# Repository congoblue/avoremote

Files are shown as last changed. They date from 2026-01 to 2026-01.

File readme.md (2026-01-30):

For Arduino Nano R4

Emulates mouse to click on a specific absolute screen location when physical button pressed.

Requires library https://github.com/jonathanedgecombe/absmouse

To program button positions, hold down REC button for 10 seconds. Mouse will move to top left of screen
and start to jiggle. Use sliders as X/Y to position the mouse pointer where required for each button then 
press the physical hardware button to record the position.

Move to REC button screen location and hold down REC button again for 10 seconds to exit program mode.

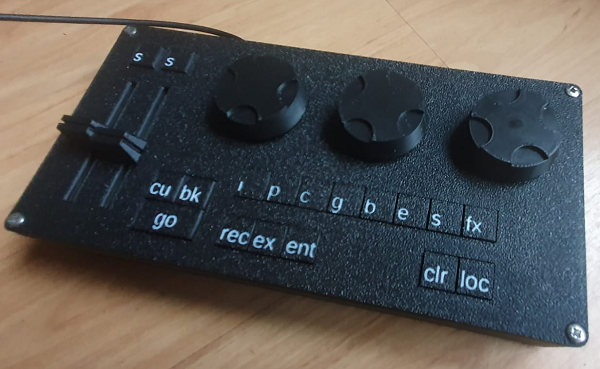
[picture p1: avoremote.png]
prototype


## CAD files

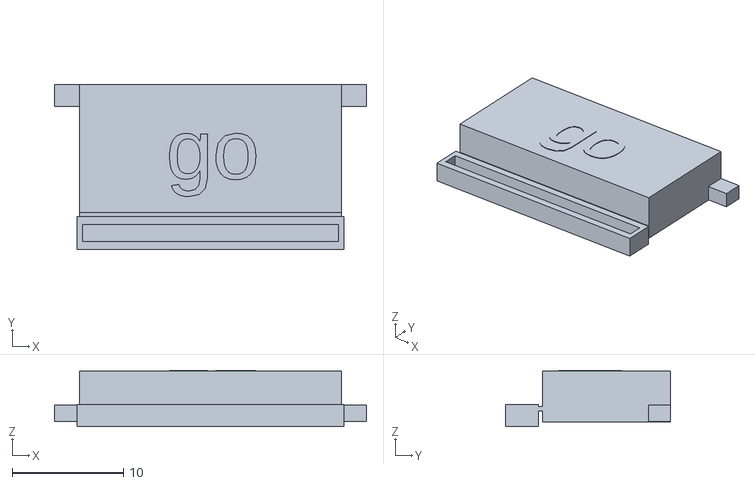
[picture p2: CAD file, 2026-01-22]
switchcaps - go.stl
28.0 x 14.8 x 5.05

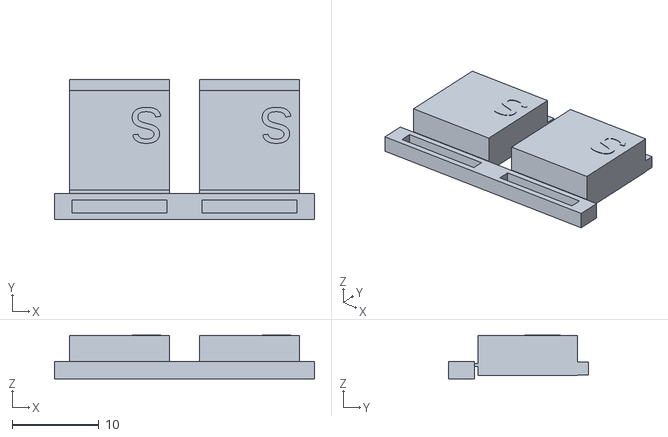
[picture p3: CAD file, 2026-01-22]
switchcaps - s.stl
30.0 x 16.1 x 5.05

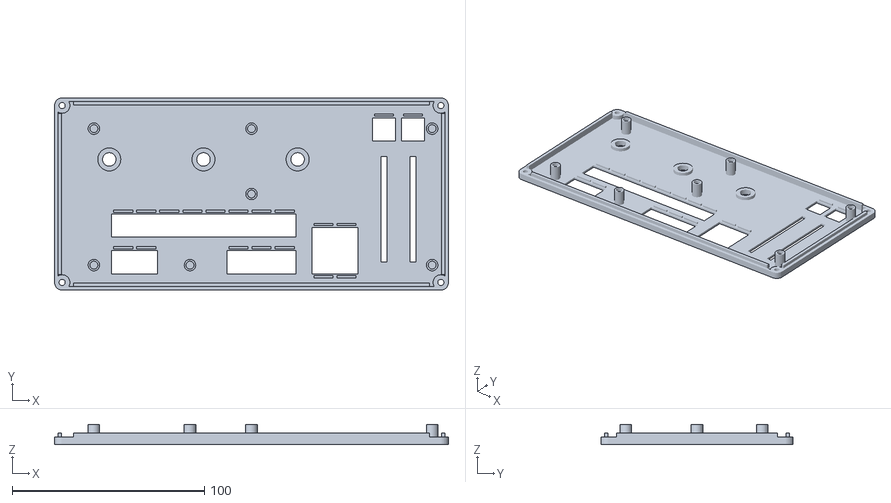
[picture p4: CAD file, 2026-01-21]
templateboxlid.stl
205.0 x 100.0 x 10.5

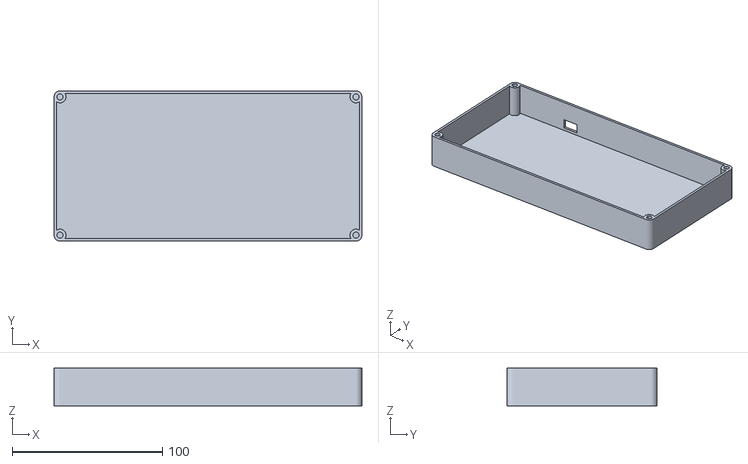
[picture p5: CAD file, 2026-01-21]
templatebox.stl
205.0 x 100.0 x 25.0

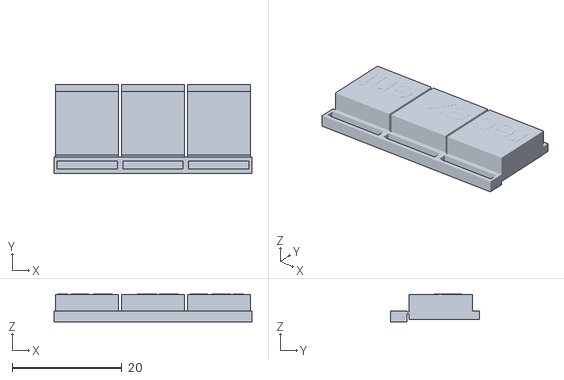
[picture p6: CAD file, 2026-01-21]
switchcaps - rec.stl
36.0 x 16.1 x 5.05

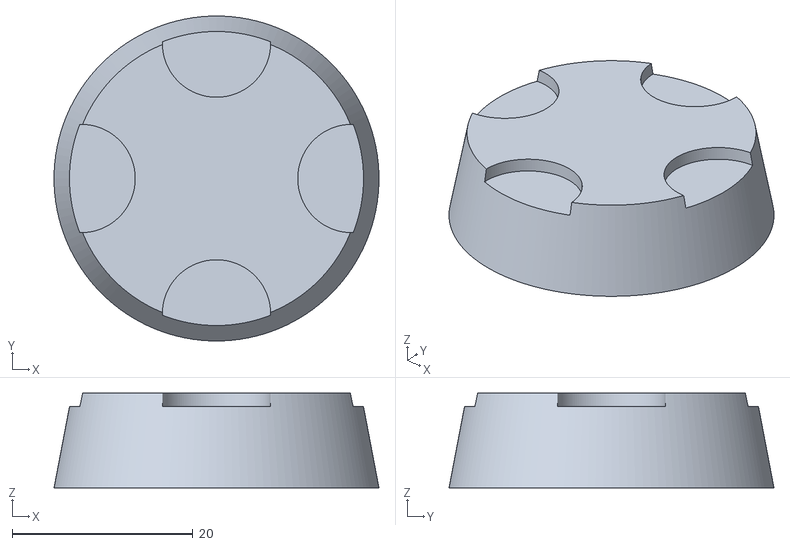
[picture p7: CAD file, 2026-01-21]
encoder_knob2.stl
36.0 x 36.0 x 10.5

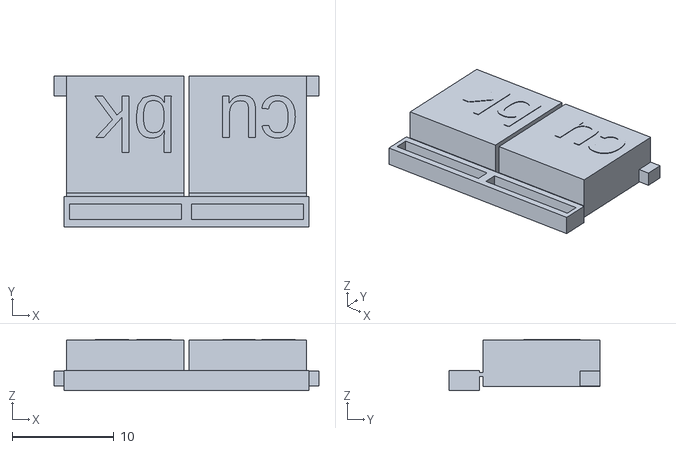
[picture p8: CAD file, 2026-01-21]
switchcaps - cue-bk.stl
26.0 x 14.8 x 5.05

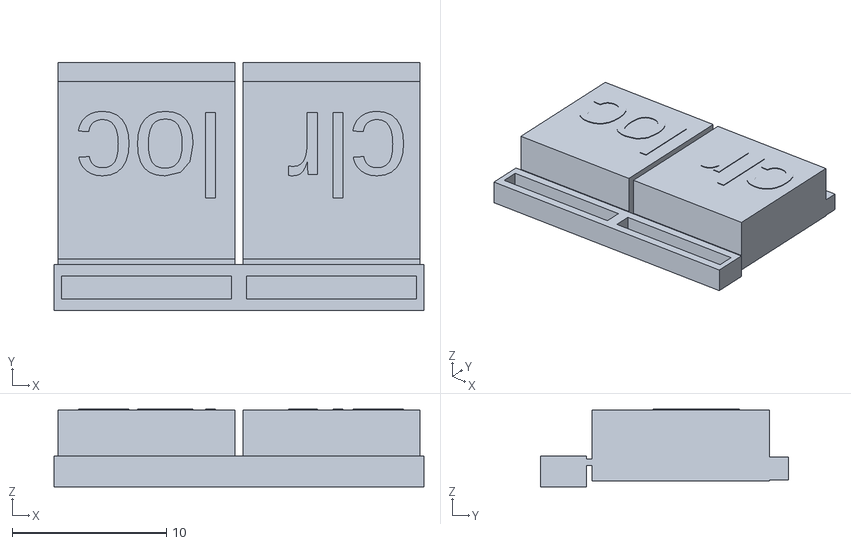
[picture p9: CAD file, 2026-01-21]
switchcaps - loc-clr.stl
24.0 x 16.1 x 5.05

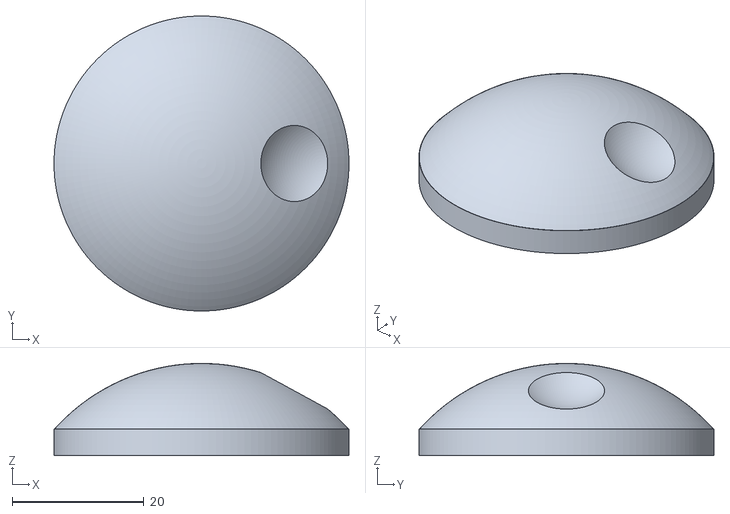
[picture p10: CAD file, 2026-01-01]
encoder_knob.stl
44.8 x 44.8 x 14.0

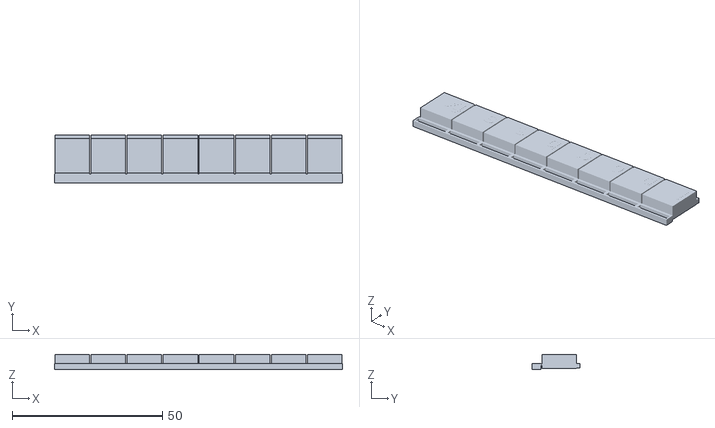
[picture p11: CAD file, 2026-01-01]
switchcaps -icgbes.stl
96.0 x 16.1 x 5.05

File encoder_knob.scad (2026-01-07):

// Definitions
// **************************

inner_dia = 12;
thick = 1.2;

//Definition of circle angular resolution
$fn = 128;  

difference() {
   union (){
    difference() {
    //translate ([0,0,0]) cylinder (h=17,r2=(inner_dia+thick*2)/2, r1=(inner_dia+thick+3)/2);
    translate ([0,0,-13]) sphere (r=30);    
    translate ([0,0,-43]) cube([100,100,100], center=true); //cut off rest of sphere
      
        }
    translate ([0,0,3]) cylinder (h=4.0,r=22.4); //bottom skirt
        
    }
    
    translate ([0,0,-thick/2]) cylinder (h=17-thick,r=6.05/2); //shaft hole
    
    
    translate ([0,0,0]) cylinder (h=6,r=inner_dia/2); //bottom recess

    translate ([17,0,19]) sphere (r=10); //finger dimple

}
     
translate ([0,4.2,11]) cube ([7,4,10], center=true); //the D shaft



 

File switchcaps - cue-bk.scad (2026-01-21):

numb=2;
cap=["bk","cu"];

difference() {

   for (i=[0:numb-1])
   {

difference() {

   union () {
    translate ([i*12,0,-1.5+1.4]) cube ( [11.5,11.5,3], center = true ); //buttons below panel

    translate ([i*12,0,-1.5+3]) cube ( [11.5,11.5,3], center = true ); //buttons above panel

    translate ([i*12,4.75,-0.8]) cube ( [14,2,1.5], center = true ); //stop below

    translate ([i*12,-6.5,-0.4]) cube ( [11.5,3,0.4], center = true ); //hinge

    translate ([i*12,-7.6,-1]) cube ( [12,3,2], center = true ); //mount bar

    translate([i*12+5, 3.75, 2.65]) linear_extrude(0.4) rotate([0,0,180]) text(cap[i],size=5.5);



   //translate ([0,-8.5,0.7]) cube ( [49,4,1.4], center = true ); //buttons

   //translate ([0,-6.5,-0.4]) cube ( [49,4,3], center = true ); //buttons


   };



   translate ([i*12,-7.6,-0.75]) cube ( [11,1.5,1.5], center = true ); //locating recess



   };

   
};

   translate ([6,6,2]) cube ( [0.5,12,12], center = true ); //locating recess


};

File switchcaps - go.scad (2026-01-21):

numb=1;
cap=["go"];

   for (i=[0:numb-1])
   {

difference() {

   union () {
    translate ([i*24,0,-1.5+1.4]) cube ( [23.5,11.5,3], center = true ); //buttons below panel

    translate ([i*24,0,-1.5+3]) cube ( [23.5,11.5,3], center = true ); //buttons above panel

    translate ([i*24,4.75,-0.8]) cube ( [28,2,1.5], center = true ); //stop below

    translate ([i*24,-6.5,-0.4]) cube ( [23.5,3,0.4], center = true ); //hinge

    translate ([i*24,-7.6,-1]) cube ( [24,3,2], center = true ); //mount bar

    translate([i*24-4, -2.75, 2.65]) linear_extrude(0.4) rotate([0,0,0]) text(cap[i],size=5.5);



   //translate ([0,-8.5,0.7]) cube ( [49,4,1.4], center = true ); //buttons

   //translate ([0,-6.5,-0.4]) cube ( [49,4,3], center = true ); //buttons


   };



   translate ([i*24,-7.6,-0.75]) cube ( [23,1.5,1.5], center = true ); //locating recess

   };

   
};

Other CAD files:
encoder_knob2.scad
switchcaps - loc-clr.scad
switchcaps - rec.scad
switchcaps - s.scad
switchcaps-icgbes.scad
templatebox.scad
templateboxlid.scad

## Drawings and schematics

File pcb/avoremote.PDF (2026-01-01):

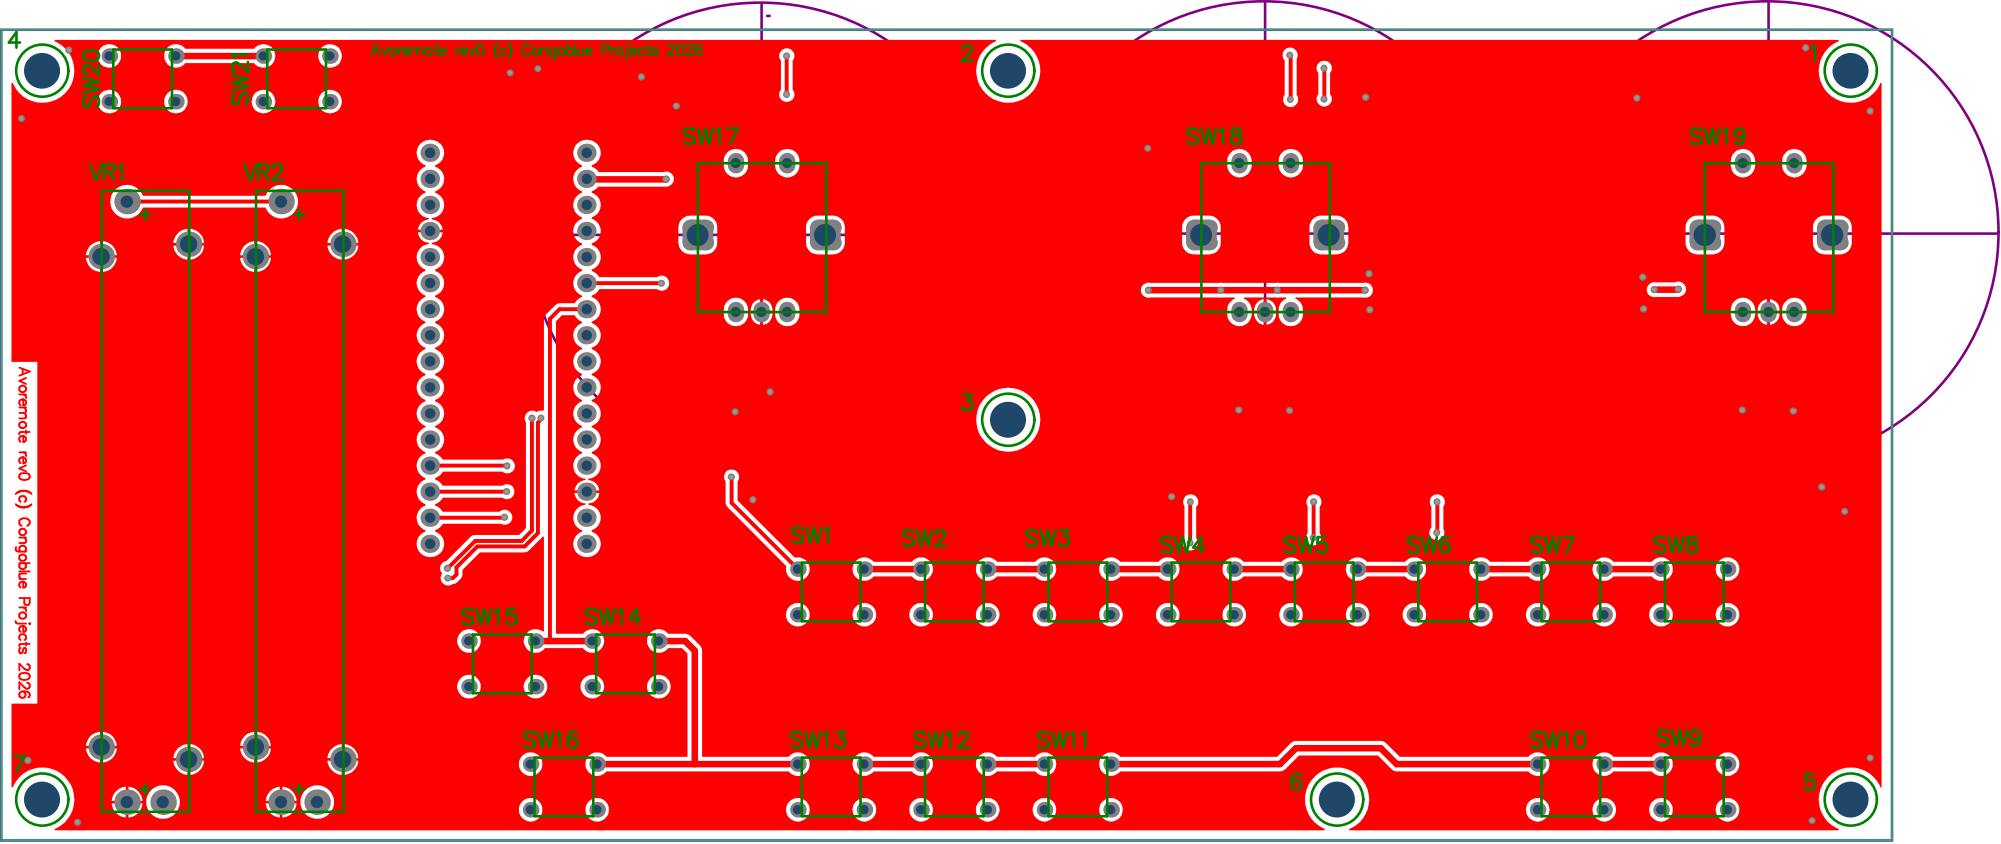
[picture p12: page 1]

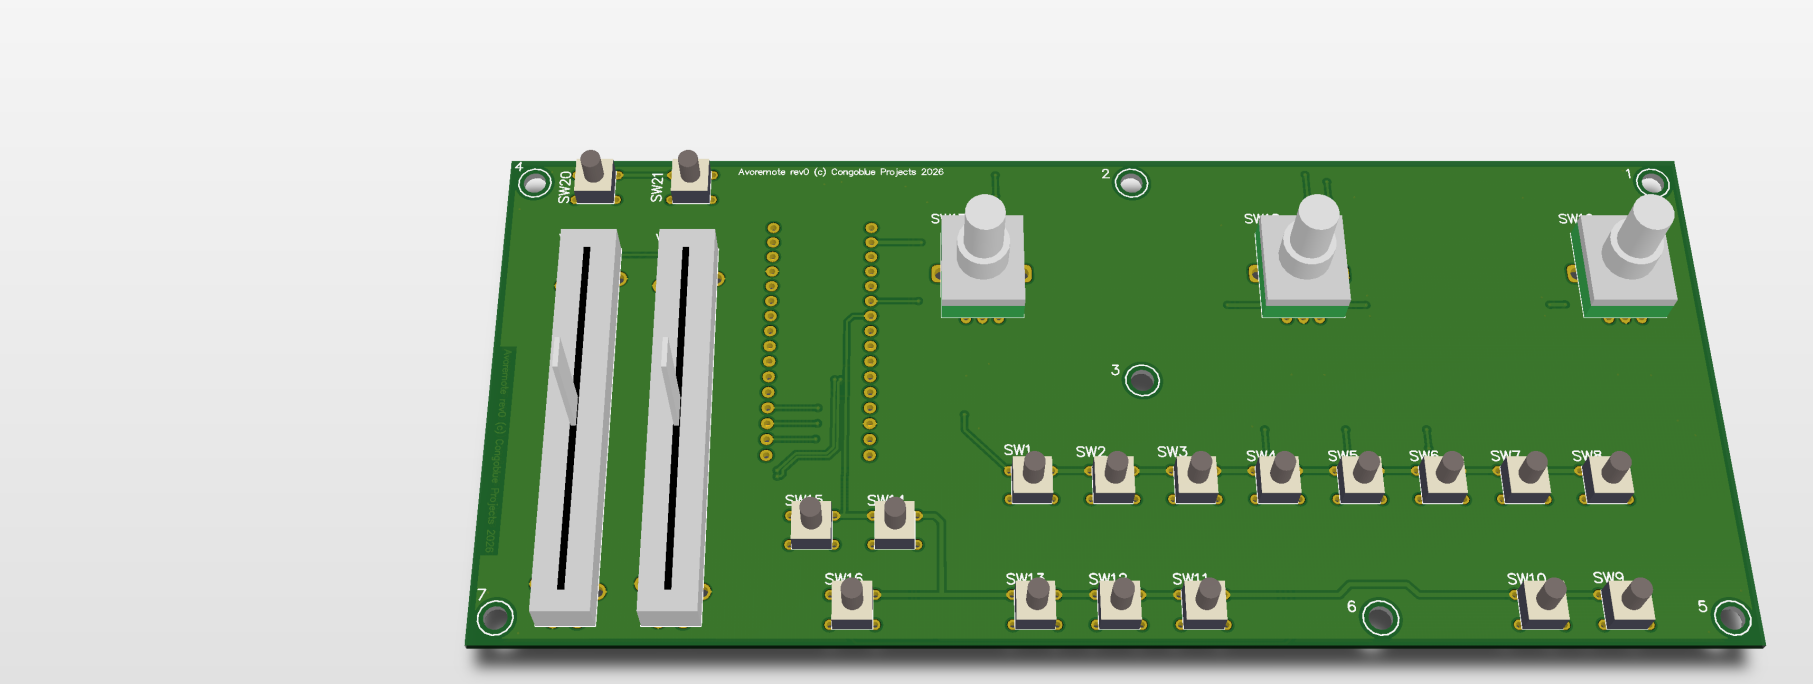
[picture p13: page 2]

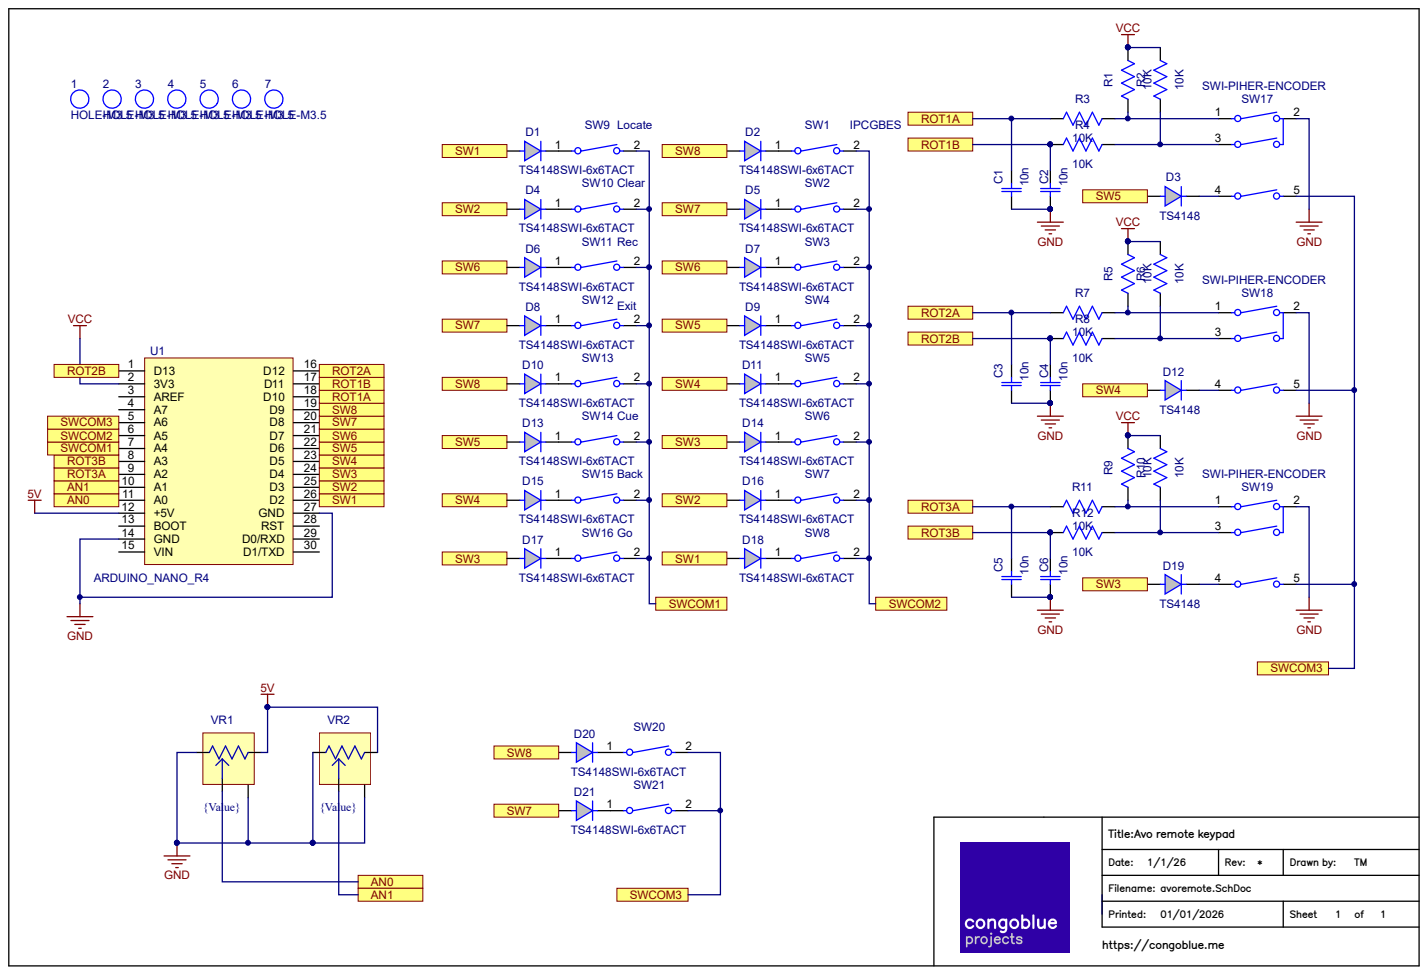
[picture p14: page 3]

ROT3A | SW3
AN1 | SW2

{Value}

Title: Avo remote keypad

Date: 1/1/26 | Rev: * | Drawn by: TM

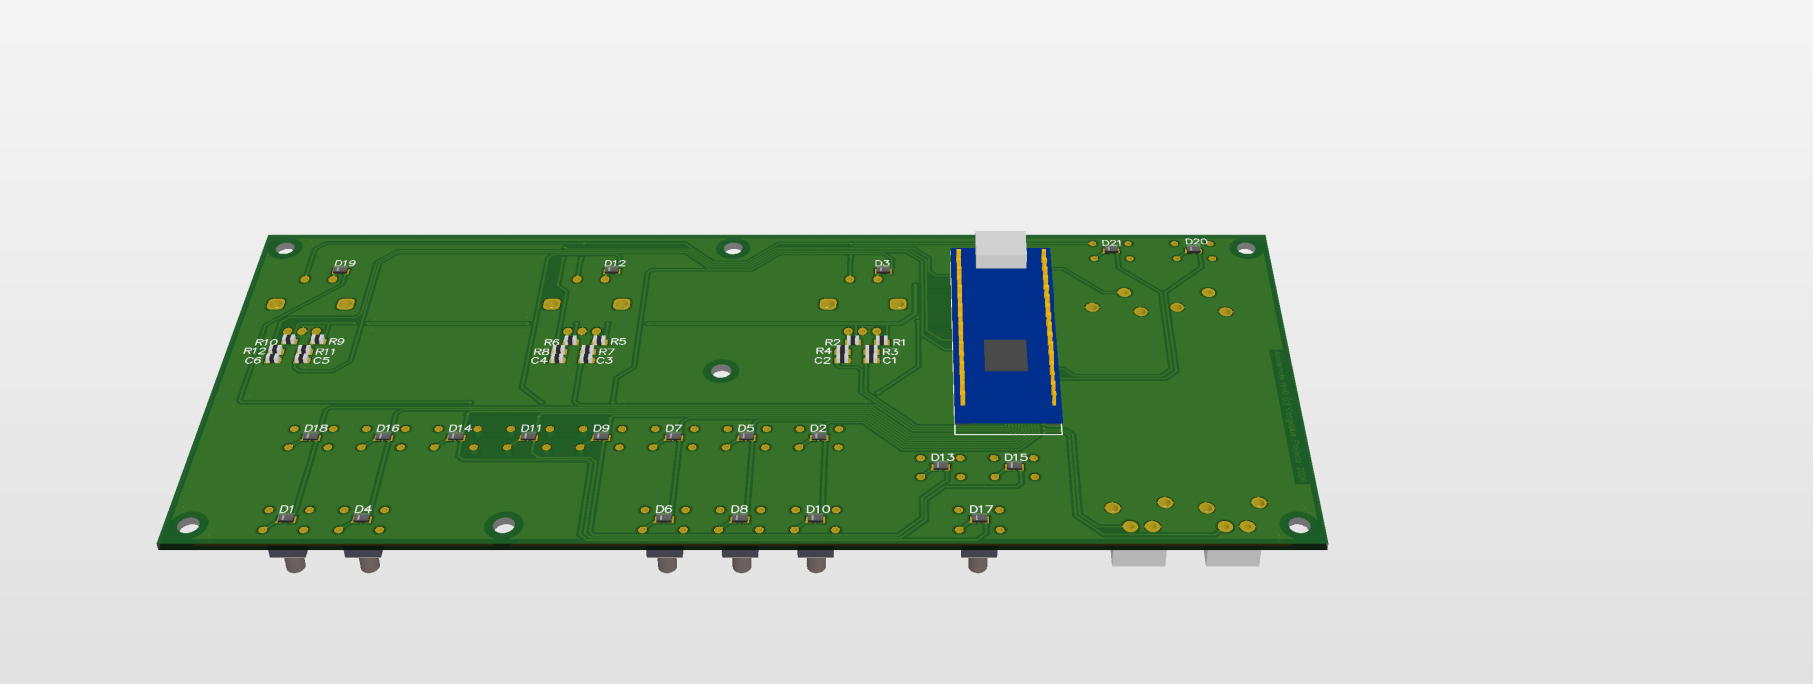
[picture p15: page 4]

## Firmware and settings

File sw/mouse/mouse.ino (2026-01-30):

#include <AbsMouse.h> 
#include <EEPROM.h>
#include <math.h> 

uint8_t pinstate=1, KeyHit=0, LastKey, seq=0, faderactive0=0, faderactive1=0;  

int32_t Enca, Encb, Encc;
int32_t timea=0,timeb=0,timec=0;
uint8_t EncaChange, EncbChange, EnccChange;
uint8_t EncaNew, EncbNew, EnccNew;

int preva0, preva1, encoffset, Swiggle;

uint32_t atime0=0,atime1=0;
int32_t fp,v;

uint32_t KeyState=0, kr=0, SetupKd=0;

uint8_t mousedn=0, SetupMode=0;

uint32_t xp[32],yp[32];


#define AN1 A6
#define AN0 A7
#define ROT3B A4
#define ROT3A A5
#define SWCOM1 A3
#define SWCOM2 A2
#define SWCOM3 A1
#define SW1 D2
#define SW2 D3
#define SW3 D4
#define SW4 D5
#define SW5 D6
#define SW6 D7
#define SW7 D8
#define SW8 D9
#define ROT1A D10
#define ROT1B D11
#define ROT2A D12
#define ROT2B D13

#define ENCODER_TIMEOUT 500
#define FADER_TIMEOUT 250  
  

void setup() { 

  AbsMouse.init(1920,1080); 

  Serial.begin(115200);

  pinMode(SW1, INPUT_PULLUP);
  pinMode(SW2, INPUT_PULLUP);
  pinMode(SW3, INPUT_PULLUP);
  pinMode(SW4, INPUT_PULLUP);
  pinMode(SW5, INPUT_PULLUP);
  pinMode(SW6, INPUT_PULLUP);
  pinMode(SW7, INPUT_PULLUP);
  pinMode(SW8, INPUT_PULLUP);

  pinMode(ROT1A, INPUT_PULLUP);
  pinMode(ROT1B, INPUT_PULLUP);
  pinMode(ROT2A, INPUT_PULLUP);
  pinMode(ROT2B, INPUT_PULLUP);
  pinMode(ROT3A, INPUT_PULLUP);
  pinMode(ROT3B, INPUT_PULLUP);

  digitalWrite(SWCOM1,1);
  digitalWrite(SWCOM2,1);
  digitalWrite(SWCOM3,1);

  pinMode(SWCOM1, OUTPUT);
  pinMode(SWCOM2, OUTPUT);
  pinMode(SWCOM3, OUTPUT);

  pinMode(LED_BUILTIN, OUTPUT);

  pinMode(AN0, INPUT); //fader 1
  pinMode(AN1, INPUT); //fader 2

  if (EEPROM.read(0)==0xAA) //eeprom is initialised
  {
    for (int i=0; i<32; i++)
    {
      xp[i]=EEPROM.read(i*4+1)+256*EEPROM.read(i*4+2);
      yp[i]=EEPROM.read(i*4+3)+256*EEPROM.read(i*4+4);
    }
  }
  else
  {
    for (int i=0; i<32; i++)
    {
      xp[i]=10+i*20;
      yp[i]=10;
    }
  }

  delay(1000); // Let USB settle 

  Serial.print("Avoremote\r\n");

} 

void EncoderPoll(void)
{
  static uint8_t prevenc=0x00;
  int8_t enca=0, encb=0, encc=0;
  uint8_t nowenc=digitalRead(ROT1A)|(digitalRead(ROT1B)<<1)|(digitalRead(ROT2A)<<2)|(digitalRead(ROT2B)<<3)|(digitalRead(ROT3A)<<4)|(digitalRead(ROT3B)<<5);

  char diff=prevenc^nowenc;

  if (diff&1)
  {
    if (prevenc&1)  //falling edge only
    {
        
        if (nowenc&2) enca=+1; else enca=-1;
        if (timea!=0) {Enca=(millis()-timea)*enca; EncaChange=1;} else EncaNew=1;
        timea=millis();
    }
  }

  if (diff&4)
  {
    if (prevenc&4) 
    {
        
        if (nowenc&8) encb=+1; else encb=-1;
        if (timeb!=0) {Encb=(millis()-timeb)*encb; EncbChange=1;} else EncbNew=1;
        timeb=millis();
    }
  }

  if (diff&16)
  {
    if (prevenc&16) 
    {
        
        if (nowenc&32) encc=+1; else encc=-1;
        if (timec!=0) {Encc=(millis()-timec)*encc; EnccChange=1;} else EnccNew=1;
        timec=millis();
    }
  }


  prevenc=nowenc;
}

uint8_t SwRead(void)  
{
   uint8_t v=0;
   if (digitalRead(SW1)) v|=1;
   if (digitalRead(SW2)) v|=2;
   if (digitalRead(SW3)) v|=4;
   if (digitalRead(SW4)) v|=8;
   if (digitalRead(SW5)) v|=16;
   if (digitalRead(SW6)) v|=32;
   if (digitalRead(SW7)) v|=64;
   if (digitalRead(SW8)) v|=128;
   return v;
}

void StorePos(uint8_t key)
{
  xp[key]=(analogRead(AN0)*1920)/1024;
  yp[key]=(analogRead(AN1)*1080)/1024;
  if (EEPROM.read(0)!=0xAA) EEPROM.write(0,0xAA); //make sure eeprom flagged as init
  EEPROM.write(key*4+1,xp[key]&0xFF); EEPROM.write(key*4+2,(xp[key]>>8)&0xFF);
  EEPROM.write(key*4+3,yp[key]&0xFF); EEPROM.write(key*4+4,(yp[key]>>8)&0xFF);
}

const uint8_t encchange[25]={
1,1,1,1,2,2,2,2,3,3, 3,4,4,4,5,5,6,6,7,8, 9,10,12,15,20
};

void loop() { 

  static uint8_t x=0;
  uint32_t a0,a1,v,i;
  static uint8_t ld=0;
  static uint8_t ks=0;

  x++;

  EncoderPoll();

  if (EncaChange)
  {
    EncaChange=0;
    if (SetupMode==0)
    {
      if (EncaNew)
      {
        EncaNew=0;
        if (mousedn!=0) {AbsMouse.release(MOUSE_LEFT); delay(100); faderactive0=0; faderactive1=0; timeb=0; timec=0;}
        AbsMouse.move(xp[24],yp[24]); 
        AbsMouse.press(MOUSE_LEFT);
        encoffset=0;
        mousedn=1;
      }
      else
      {
        //Serial.println(Enca);
        if (abs(Enca)>100) v=1; else v=encchange[(100-abs(Enca))/4];
        if (Enca>0) 
        {
          encoffset+=v; 
          if (xp[24]+encoffset>1919) {AbsMouse.release(MOUSE_LEFT); encoffset=0; EncaNew=1;}
        }
        else 
        {
          if (encoffset+xp[24]>v) encoffset-=v; else encoffset=xp[24];
        }      
        AbsMouse.move(xp[24]+encoffset,yp[24]); 
      }
    }
    else
    {
       StorePos(24);
    }

  }

  if (EncbChange)
  {
    EncbChange=0;
    if (SetupMode==0)
    {
      if (EncbNew)
      {
        EncbNew=0;
        if (mousedn!=0) {AbsMouse.release(MOUSE_LEFT); delay(100); faderactive0=0; faderactive1=0; timea=0; timec=0;}
        AbsMouse.move(xp[25],yp[25]); 
        AbsMouse.press(MOUSE_LEFT);
        encoffset=0;
        mousedn=1;
      }
      else
      {
        if (abs(Encb)>100) v=1; else v=encchange[(100-abs(Encb))/4];
        if (Encb>0) 
        {
          encoffset+=v; 
          if (xp[25]+encoffset>1919) {AbsMouse.release(MOUSE_LEFT); encoffset=0; EncbNew=1;}
        }
        else 
        {
          if (encoffset+xp[25]>v) encoffset-=v; else encoffset=xp[25];
        }      
        AbsMouse.move(xp[25]+encoffset,yp[25]); 
      }
    }
    else
    {
       StorePos(25);
    }

  }

  if (EnccChange)
  {
    EnccChange=0;
    if (SetupMode==0)
    {
      if (EnccNew)
      {
        EnccNew=0;
        if (mousedn!=0) {AbsMouse.release(MOUSE_LEFT); delay(100); faderactive0=0; faderactive1=0; timea=0; timeb=0;}
        AbsMouse.move(xp[26],yp[26]); 
        AbsMouse.press(MOUSE_LEFT);
        encoffset=0;
        mousedn=1;
      }
      else
      {
        if (abs(Encc)>100) v=1; else v=encchange[(100-abs(Encc))/4];
        if (Encc>0) 
        {
          encoffset+=v; 
          if (xp[26]+encoffset>1919) {AbsMouse.release(MOUSE_LEFT); encoffset=0; EnccNew=1;}
        }
        else 
        {
          if (encoffset+xp[26]>v) encoffset-=v; else encoffset=xp[26];
        }      
        AbsMouse.move(xp[26]+encoffset,yp[26]); 
      }
    }
    else
    {
       StorePos(26);
    }

  }


  if (timea!=0) if ((millis()-timea)>ENCODER_TIMEOUT) 
  {
    timea=0;
    AbsMouse.release(MOUSE_LEFT);
    mousedn=0;
  }
  if (timeb!=0) if ((millis()-timeb)>ENCODER_TIMEOUT) 
  {
    timeb=0;
    AbsMouse.release(MOUSE_LEFT);
    mousedn=0;
  }
  if (timec!=0) if ((millis()-timec)>ENCODER_TIMEOUT) 
  {
    timec=0;
    AbsMouse.release(MOUSE_LEFT);
    mousedn=0;
  }

  if (x>=10)
  {
    x=0;

  //key scan
  if (ks==0) 
  {
    kr&=0xFFFF00;
    kr|=(~SwRead())&0xFF;
    ks=1;
    digitalWrite(SWCOM1,1);
    digitalWrite(SWCOM2,0);
  }
  else if (ks==1) 
  {
    kr&=0xFF00FF;
    kr|=((~SwRead())<<8)&0x00FF00;
    ks=2;
    digitalWrite(SWCOM2,1);
    digitalWrite(SWCOM3,0);
  }
  else if (ks==2) 
  {
    kr&=0x00FFFF;
    kr|=((~SwRead())<<16)&0xFF0000;
    ks=0;
    digitalWrite(SWCOM3,1);
    digitalWrite(SWCOM1,0);

    //check if anything has changed
    if (kr!=KeyState)
    {
       if (kr>KeyState) //newly pressed
       {
         KeyHit=1;
         v=kr^KeyState;
         for (i=0; i<24; i++) if (v&(1<<i)) LastKey=i;
       }
       KeyState=kr;
       
       //Serial.print(KeyState,HEX);
    }
  }

  //check for entering setup mode
  if (KeyState==0x80)
  {
     if (SetupKd!=0)
     {
        if (millis()-SetupKd>10000) 
        {
          if (SetupMode==0) 
          {
            SetupMode=1; 
            Serial.println("Start Setup mode");
            SetupKd=0;
          }
          else 
          {
            SetupMode=0;
            Serial.println("End Setup mode");
            SetupKd=0;
            AbsMouse.move(10,10); 
          }
        }
     }
     else 
     {
        SetupKd=millis();
     }
  }
  else
     SetupKd=0;
  
  //diagnostic

   if (KeyHit!=0)
   {
      //KeyHit=0;
      Serial.println(LastKey);
   }

   //flash the LED
   ld++; 
   if (ld==50) {digitalWrite(LED_BUILTIN,1); Swiggle=2;}
   if (ld>=100) 
   {
      ld=0; 
      digitalWrite(LED_BUILTIN,0); 
      Swiggle=0;
      //Serial.println(nowenc,HEX);
   }

   if (KeyHit!=0)
   {
      KeyHit=0;
      if (SetupMode==0)
      {
        AbsMouse.move(xp[LastKey],yp[LastKey]); 
        AbsMouse.press(MOUSE_LEFT);
        delay(100); 
        AbsMouse.release(MOUSE_LEFT);
        faderactive0=0;
        delay(100); 
      }
      else //setupmode. Store the position
      {         
         StorePos(LastKey);
      }
   }

   if (SetupMode==0)
   {
    a0=analogRead(AN0);
    if (abs(a0-preva0)>20)
    {
        //Serial.println(a0);
        preva0=a0;
        if (faderactive0==0) fp=a0; //this is a new move starting. Remember where we started off from
        atime0=millis();
        v=yp[23]+120+(112*(int32_t)(fp-a0)/1024);
        if (v>1079) v=1079; //stay on the screen
        //Serial.println(v);
        AbsMouse.move(xp[23], v);
        if (faderactive0==0) 
        {
              faderactive0=1;
              if (mousedn!=0) {AbsMouse.release(MOUSE_LEFT); faderactive1=0; timea=0; timeb=0; timec=0;}
              AbsMouse.press(MOUSE_LEFT);
              mousedn=1;
        }
    }

    if ((faderactive0!=0)&&((millis()-atime0)>FADER_TIMEOUT))
    {
          AbsMouse.release(MOUSE_LEFT);
          mousedn=0;
          faderactive0=0;
    }

    a1=analogRead(AN1);
    if (abs(a1-preva1)>20)
    {
        //Serial.println(a1);
        preva1=a1;
        if (faderactive1==0) fp=a1; //this is a new move starting. Remember where we started off from
        atime1=millis();
        v=yp[22]+120+(112*(int32_t)(fp-a1)/1024);
        if (v>1079) v=1079; //stay on the screen
        AbsMouse.move(xp[22], v);
        if (faderactive1==0) 
        {
              faderactive1=1;
              if (mousedn!=0) {AbsMouse.release(MOUSE_LEFT); faderactive0=0; timea=0; timeb=0; timec=0;}
              AbsMouse.press(MOUSE_LEFT);
              mousedn=1;
        }
    }

    if ((faderactive1!=0)&&((millis()-atime1)>FADER_TIMEOUT))
    {
          AbsMouse.release(MOUSE_LEFT);
          mousedn=0;
          faderactive1=0;
    }
   }
   else //setup mode. Sliders move the cursor
   {
       a0=analogRead(AN0);
       a1=analogRead(AN1);
       AbsMouse.move((a0*1920)/1024+Swiggle, (a1*1080)/1024);
   }

  }
  

  delay(1); 

} 

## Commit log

2026-01-07 change pcb pillars so they are connected to the lid
    [encoder_knob.scad, templateboxlid.scad, templateboxlid.stl]
2026-01-21 Fix 3d files and get some software to work
    [templatebox.scad, templatebox.stl, templateboxlid.scad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]
2026-01-21 Update PCB
    [avoremote.PcbDoc, avoremote.PrjPCB, avoremote.SchDoc]
2026-01-22 sw changes
    [switchcaps - go.stl, switchcaps - s.scad, switchcaps - s.stl]
2026-01-30 Make encoders work at screen edge
